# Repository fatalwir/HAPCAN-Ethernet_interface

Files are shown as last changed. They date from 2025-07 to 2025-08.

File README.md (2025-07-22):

# HAPCAN-Ethernet_interface

## TODO:
 - There is an OpenWRT package to program STM32s directly using the Mediatek SoC GPIO pins. Implement that? [https://hackaday.io/project/166859-prism/log/166980-braaains]
 - Replace the MCP3422 ADC by the MCP3423 because of the I2C address collision with BQ32000.
 - Look into replacing the CANable interface by MCP2515?

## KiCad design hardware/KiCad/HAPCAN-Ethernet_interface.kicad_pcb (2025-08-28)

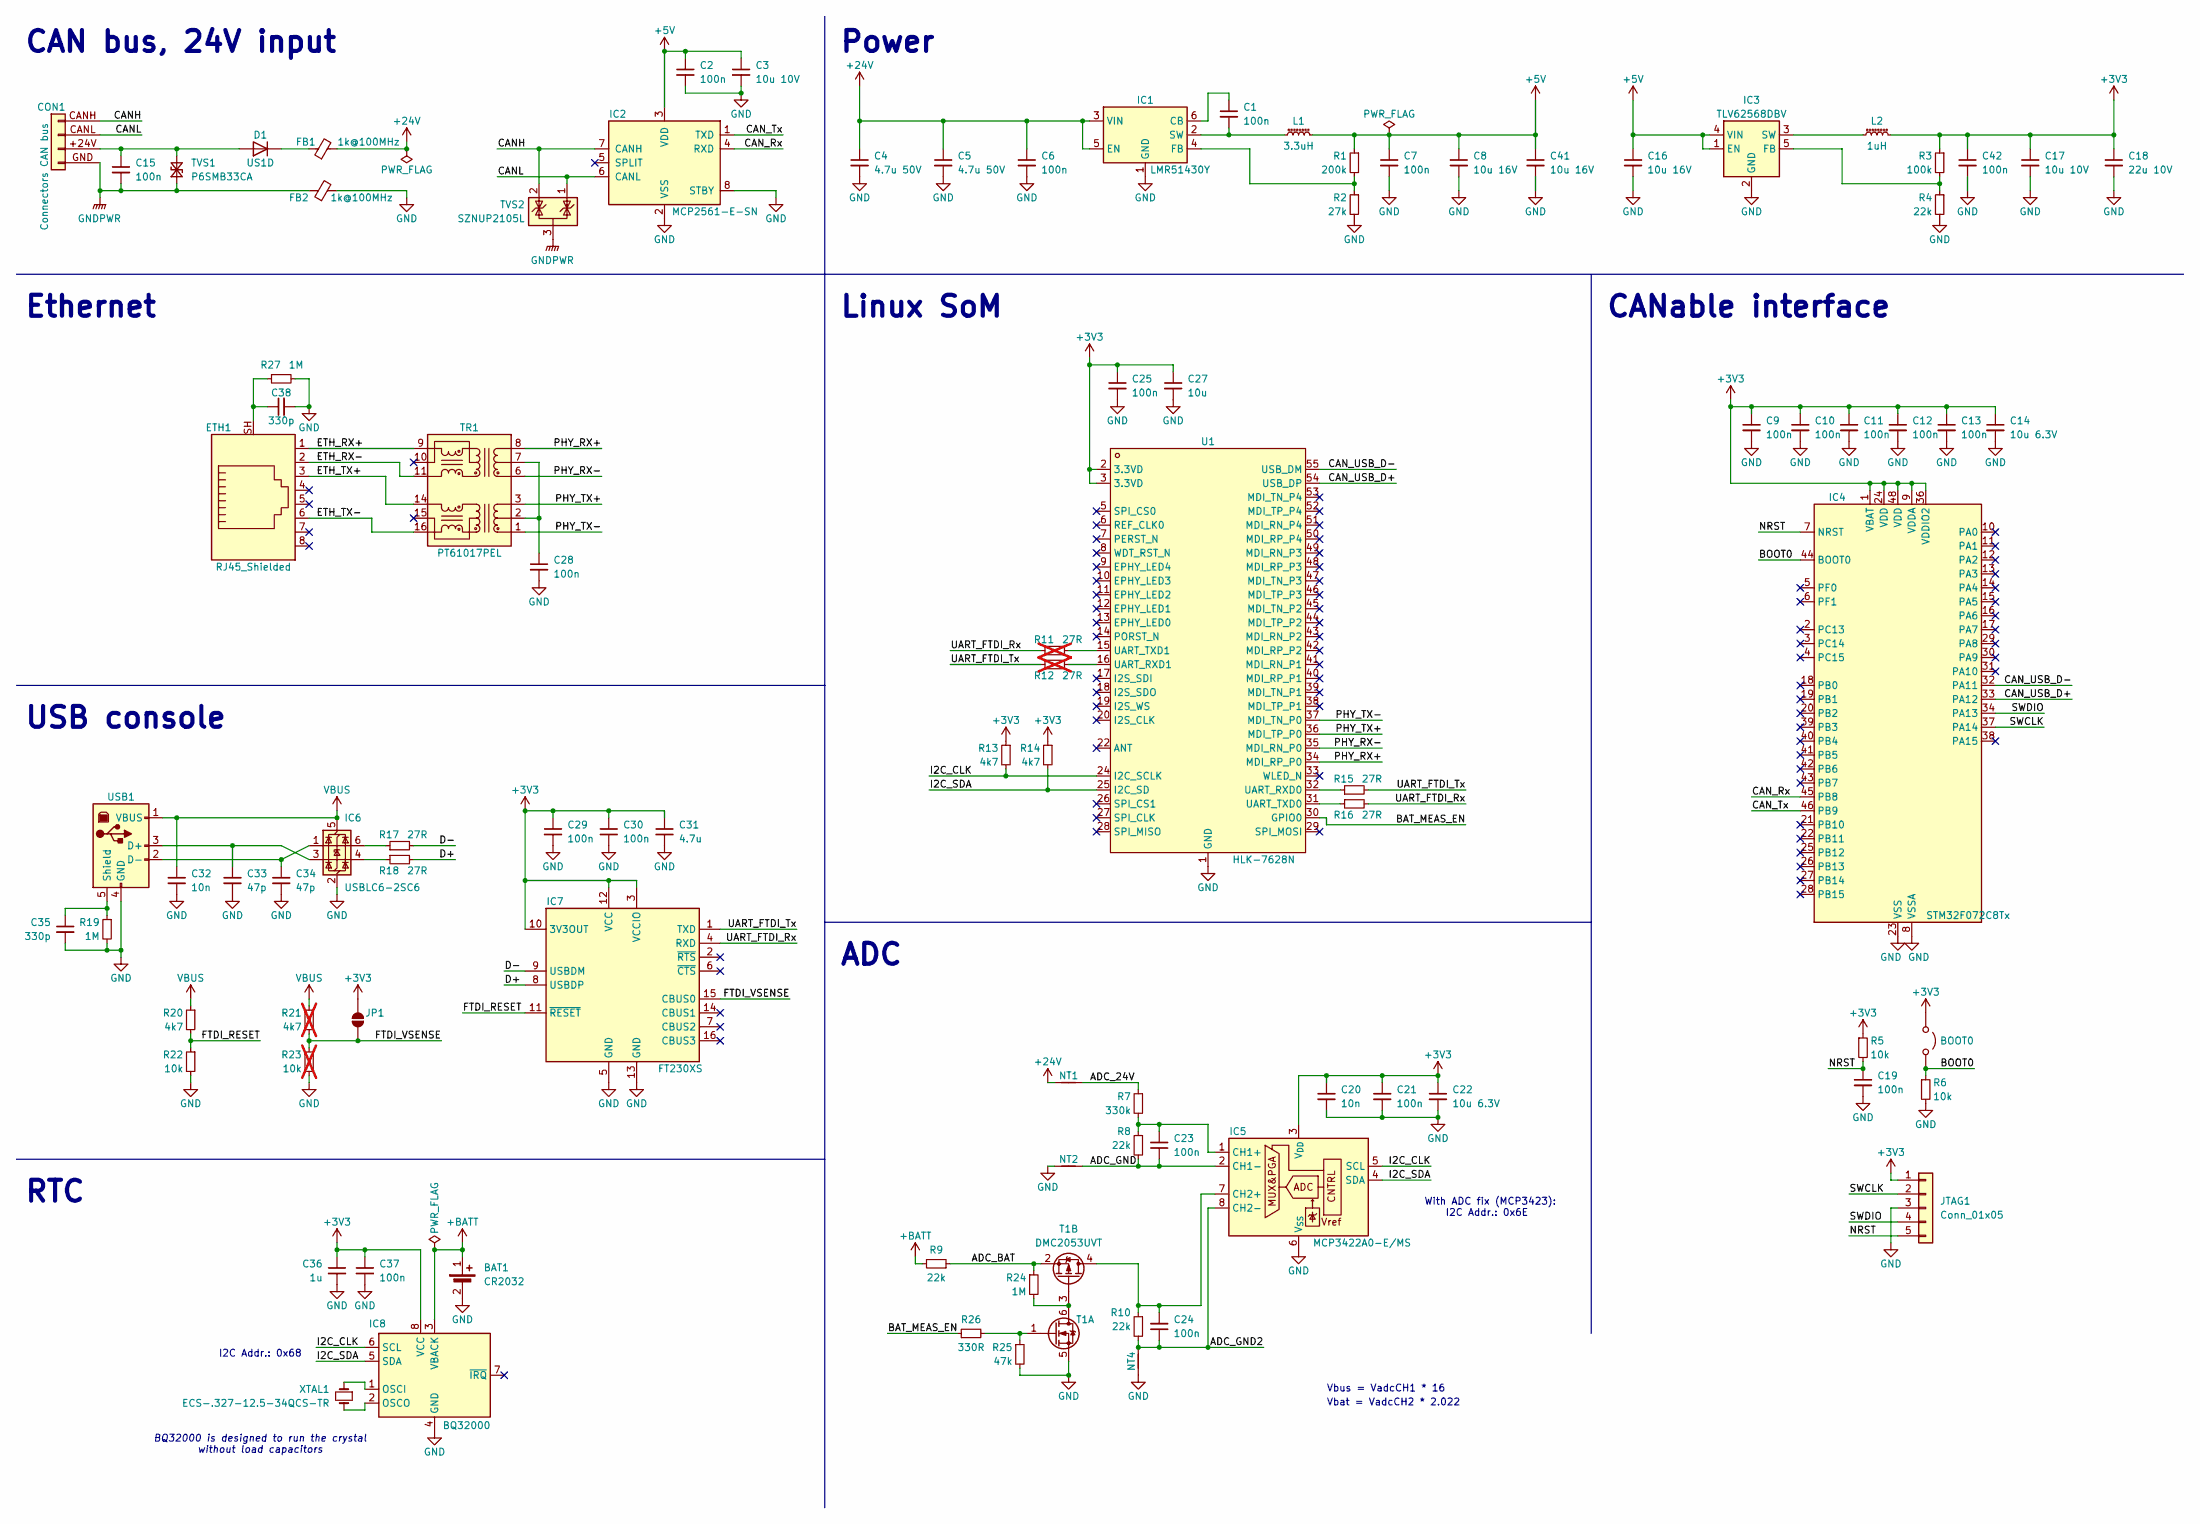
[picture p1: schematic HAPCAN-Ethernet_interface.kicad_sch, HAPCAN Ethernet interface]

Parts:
BAT1: CR2032; 1074
BOOT0: Jumper_2_Open; PinHeader_1x02_P2.54mm_Vertical
C1, C2, C6, C7, C9, C10, C11, C12, C13, C15, C19, C21, C23, C24, C25, C28, C29, C30, C37, C42: 100n; C_0603_1608Metric_Pad1.08x0.95mm_HandSolder
C3: 10u 10V; C_1206_3216Metric_Pad1.33x1.80mm_HandSolder
C4, C5: 4.7u 50V; C_1210_3225Metric_Pad1.33x2.70mm_HandSolder
C8, C16, C41: 10u 16V; C_1210_3225Metric_Pad1.33x2.70mm_HandSolder
C14, C22: 10u 6.3V; C_1206_3216Metric_Pad1.33x1.80mm_HandSolder
C17: 10u 10V; C_1210_3225Metric_Pad1.33x2.70mm_HandSolder
C18: 22u 10V; C_1210_3225Metric_Pad1.33x2.70mm_HandSolder
C20, C32: 10n; C_0603_1608Metric_Pad1.08x0.95mm_HandSolder
C27: 10u; C_1206_3216Metric_Pad1.33x1.80mm_HandSolder
C31: 4.7u; C_1206_3216Metric_Pad1.33x1.80mm_HandSolder
C33, C34: 47p; C_0603_1608Metric_Pad1.08x0.95mm_HandSolder
C35, C38: 330p; C_0603_1608Metric_Pad1.08x0.95mm_HandSolder
C36: 1u; C_0805_2012Metric_Pad1.18x1.45mm_HandSolder
CON1: Connectors CAN bus; Conn_CAN-Bus
D1: US1D; D_SMA_Handsoldering
ETH1: RJ45_Shielded; RJ45_Ninigi_GE
FB1, FB2: 1k@100MHz; L_0805_2012Metric_Pad1.15x1.40mm_HandSolder
IC1: LMR51430Y; SOT-23-6
IC2: MCP2561-E-SN; SOIC-8_3.9x4.9mm_P1.27mm
IC3: TLV62568DBV; SOT-23-5
IC4: STM32F072C8Tx; LQFP-48_7x7mm_P0.5mm
IC5: MCP3422A0-E/MS; MSOP-8_3x3mm_P0.65mm
IC6: USBLC6-2SC6; SOT-23-6_Handsoldering
IC7: FT230XS; SSOP-16_3.9x4.9mm_P0.635mm
IC8: BQ32000; SOIC-8_3.9x4.9mm_P1.27mm
JP1: SolderJumper_2_Open; SolderJumper-2_P1.3mm_Open_TrianglePad1.0x1.5mm
JTAG1: Conn_01x05; PinHeader_1x05_P2.54mm_Vertical
L1: 3.3uH; SPM7054VT
L2: 1uH; SPM7054VT
NT1, NT2, NT4: NetTie_2; NetTie-2_SMD_Pad0.5mm
R1: 200k; R_0603_1608Metric_Pad0.98x0.95mm_HandSolder
R2: 27k; R_0603_1608Metric_Pad0.98x0.95mm_HandSolder
R3: 100k; R_0603_1608Metric_Pad0.98x0.95mm_HandSolder
R4, R8, R9, R10: 22k; R_0603_1608Metric_Pad0.98x0.95mm_HandSolder
R5, R6, R22: 10k; R_0603_1608Metric_Pad0.98x0.95mm_HandSolder
R7: 330k; R_0603_1608Metric_Pad0.98x0.95mm_HandSolder
R11, R12: 27R; R_0603_1608Metric_Pad0.98x0.95mm_HandSolder; not fitted
R13, R14, R20: 4k7; R_0603_1608Metric_Pad0.98x0.95mm_HandSolder
R15, R16, R17, R18: 27R; R_0603_1608Metric_Pad0.98x0.95mm_HandSolder
R19, R24, R27: 1M; R_0603_1608Metric_Pad0.98x0.95mm_HandSolder
R21: 4k7; R_0603_1608Metric_Pad0.98x0.95mm_HandSolder; not fitted
R23: 10k; R_0603_1608Metric_Pad0.98x0.95mm_HandSolder; not fitted
R25: 47k; R_0603_1608Metric_Pad0.98x0.95mm_HandSolder
R26: 330R; R_0603_1608Metric_Pad0.98x0.95mm_HandSolder
T1: DMC2053UVT; TSOT-23-6
TR1: PT61017PEL; Transformer_Ethernet_Bourns_PT61017PEL
TVS1: P6SMB33CA; D_SMB_Handsoldering
TVS2: SZNUP2105L; SOT-23-3
U1: HLK-7628N
USB1: https://www.aliexpress.com/item/4000926155068.html; PinHeader_1x05_P2.54mm_Vertical
XTAL1: ECS-.327-12.5-34QCS-TR; Crystal_SMD_EuroQuartz_EQ161-2Pin_3.2x1.5mm_HandSoldering

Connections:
+3V3: BOOT0.1 (A), C9.1, C10.1, C11.1, C12.1, C13.1, C14.1, C17.1, C18.1, C20.1, C21.1, C22.1, C25.1, C27.1, C29.1, C30.1, C31.1, C36.1, C37.1, C42.1, IC4.1 (VBAT), IC4.9 (VDDA), IC4.24 (VDD), IC4.36 (VDDIO2), IC4.48 (VDD), IC5.3 (V_{DD}), IC7.3 (VCCIO), IC7.10 (3V3OUT), IC7.12 (VCC), IC8.8 (VCC), JP1.2 (B), JTAG1.1, L2.2, R3.1, R5.1, R13.1, R14.1, U1.2 (3.3VD), U1.3 (3.3VD)
+5V: C2.1, C3.1, C7.1, C8.1, C16.1, C41.1, IC2.3 (VDD), IC3.1 (EN), IC3.4 (VIN), L1.2, R1.1
+24V: C4.1, C5.1, C6.1, FB1.2, IC1.3 (VIN), IC1.5 (EN), NT1.1
+BATT: BAT1.1 (+), IC8.3 (VBACK), R9.2
/ADC_24V: NT1.2, R7.1
/ADC_BAT: R9.1, R24.1, T1.2 (S)
/ADC_GND: C23.1, IC5.2 (CH1-), NT2.2, R8.2
/ADC_GND2: C24.1, IC5.8 (CH2-), NT4.2, R10.2
/BAT_MEAS_EN: R26.1, U1.30 (GPIO0)
/BOOT0: BOOT0.2 (B), IC4.44 (BOOT0), R6.1
/CANH: CON1.CANH, IC2.7 (CANH), TVS2.2 (K)
/CANL: CON1.CANL, IC2.6 (CANL), TVS2.1 (K)
/CAN_Rx: IC2.4 (RXD), IC4.45 (PB8)
/CAN_Tx: IC2.1 (TXD), IC4.46 (PB9)
/CAN_USB_D+: IC4.33 (PA12), U1.54 (USB_DP)
/CAN_USB_D-: IC4.32 (PA11), U1.55 (USB_DM)
/D+: IC7.8 (USBDP), R18.2
/D-: IC7.9 (USBDM), R17.2
/ETH_RX+: ETH1.1, TR1.9 (RX-)
/ETH_RX-: ETH1.2, TR1.11 (RX+)
/ETH_TX+: ETH1.3, TR1.14 (TX-)
/ETH_TX-: ETH1.6, TR1.16 (TX+)
/FTDI_RESET: IC7.11 (~RESET), R20.2, R22.1
/FTDI_VSENSE: IC7.15 (CBUS0), JP1.1 (A), R21.2, R23.1
/I2C_CLK: IC5.5 (SCL), IC8.6 (SCL), R13.2, U1.24 (I2C_SCLK)
/I2C_SDA: IC5.4 (SDA), IC8.5 (SDA), R14.2, U1.25 (I2C_SD)
/NRST: C19.1, IC4.7 (NRST), JTAG1.5, R5.2
/PHY_RX+: TR1.8 (RD-), U1.34 (MDI_RP_P0)
/PHY_RX-: TR1.6 (RD+), U1.35 (MDI_RN_P0)
/PHY_TX+: TR1.3 (TD-), U1.36 (MDI_TP_P0)
/PHY_TX-: TR1.1 (TD+), U1.37 (MDI_TN_P0)
/SWCLK: IC4.37 (PA14), JTAG1.2
/SWDIO: IC4.34 (PA13), JTAG1.4
/UART_FTDI_Rx: IC7.4 (RXD), R11.1, R16.2
/UART_FTDI_Tx: IC7.1 (TXD), R12.1, R15.2
GND: BAT1.2 (-), C2.2, C3.2, C4.2, C5.2, C6.2, C7.2, C8.2, C9.2, C10.2, C11.2, C12.2, C13.2, C14.2, C16.2, C17.2, C18.2, C19.2, C20.2, C21.2, C22.2, C25.2, C27.2, C28.2, C29.2, C30.2, C31.2, C32.2, C33.2, C34.2, C35.2, C36.2, C37.2, C38.2, C41.2, C42.2, FB2.2, IC1.1 (GND), IC2.2 (VSS), IC2.8 (STBY), IC3.2 (GND), IC4.8 (VSSA), IC4.23 (VSS), IC4.35 (VSS), IC4.47 (VSS), IC5.6 (V_{SS}), IC6.2 (GND), IC7.5 (GND), IC7.13 (GND), IC8.4 (GND), JTAG1.3, NT2.1, NT4.1, R2.2, R4.2, R6.2, R19.2, R22.2, R23.2, R25.2, R27.2, T1.5 (S), U1.1 (GND), U1.4 (GND), U1.21 (GND), U1.23 (GND), U1.56 (GND), USB1.4 (GND)
GNDPWR: C15.2, CON1.GND, FB2.1, TVS1.1 (A1), TVS2.3 (A)
unnamed: C38.1, ETH1.SH, R27.1
unnamed: C15.1, CON1.+24V, D1.2 (A), TVS1.2 (A2)
unnamed: D1.1 (K), FB1.1
unnamed: C1.1, IC1.6 (CB)
unnamed: IC1.4 (FB), R1.2, R2.1
unnamed: C1.2, IC1.2 (SW), L1.1
unnamed: IC3.5 (FB), R3.2, R4.1
unnamed: IC3.3 (SW), L2.1
unnamed: C23.2, IC5.1 (CH1+), R7.2, R8.1
unnamed: C24.2, IC5.7 (CH2+), R10.1, T1.4 (D)
unnamed: IC6.6 (I/O1), R17.1
unnamed: IC6.4 (I/O2), R18.1
unnamed: IC8.1 (OSCI), XTAL1.1
unnamed: IC8.2 (OSCO), XTAL1.2
unnamed: R24.2, T1.3 (G), T1.6 (D)
unnamed: R25.1, R26.2, T1.1 (G)
unnamed: C28.1, TR1.2 (C_TD), TR1.7 (C_RD)
unnamed: R15.1, U1.32 (UART_RXD0)
unnamed: R12.2, U1.16 (UART_RXD1)
unnamed: R16.1, U1.31 (UART_TXD0)
unnamed: R11.2, U1.15 (UART_TXD1)
unnamed: C33.1, IC6.3 (I/O2), USB1.3 (D+)
unnamed: C34.1, IC6.1 (I/O1), USB1.2 (D-)
unnamed: C35.1, R19.1, USB1.5 (Shield)
VBUS: C32.1, IC6.5 (VBUS), R20.1, R21.1, USB1.1 (VBUS)

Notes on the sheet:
Power
With ADC fix (MCP3423): I2C Addr.: 0x6E
BQ32000 is designed to run the crystal without load capacitors
Linux SoM
ADC
CAN bus, 24V input
CANable interface
I2C Addr.: 0x68
Vbus = VadcCH1 * 16
Vbat = VadcCH2 * 2.022
USB console
RTC
Ethernet

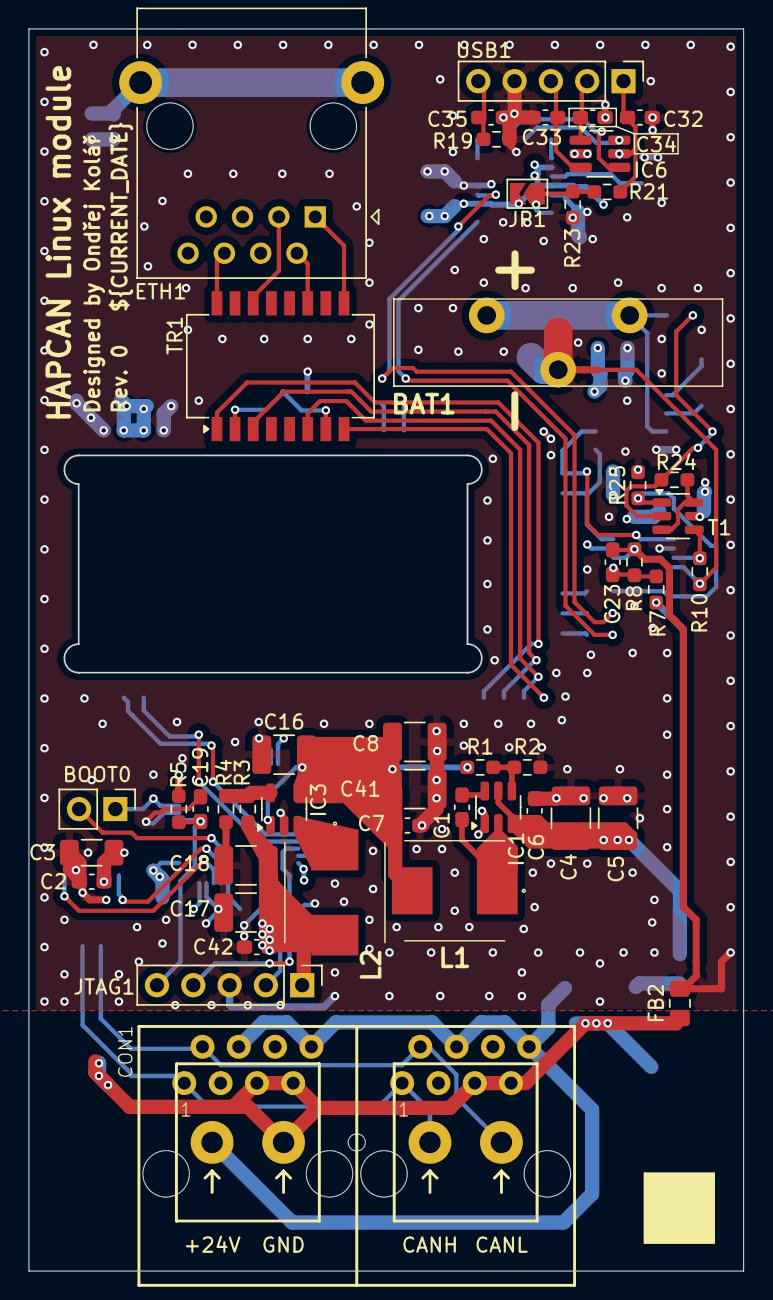
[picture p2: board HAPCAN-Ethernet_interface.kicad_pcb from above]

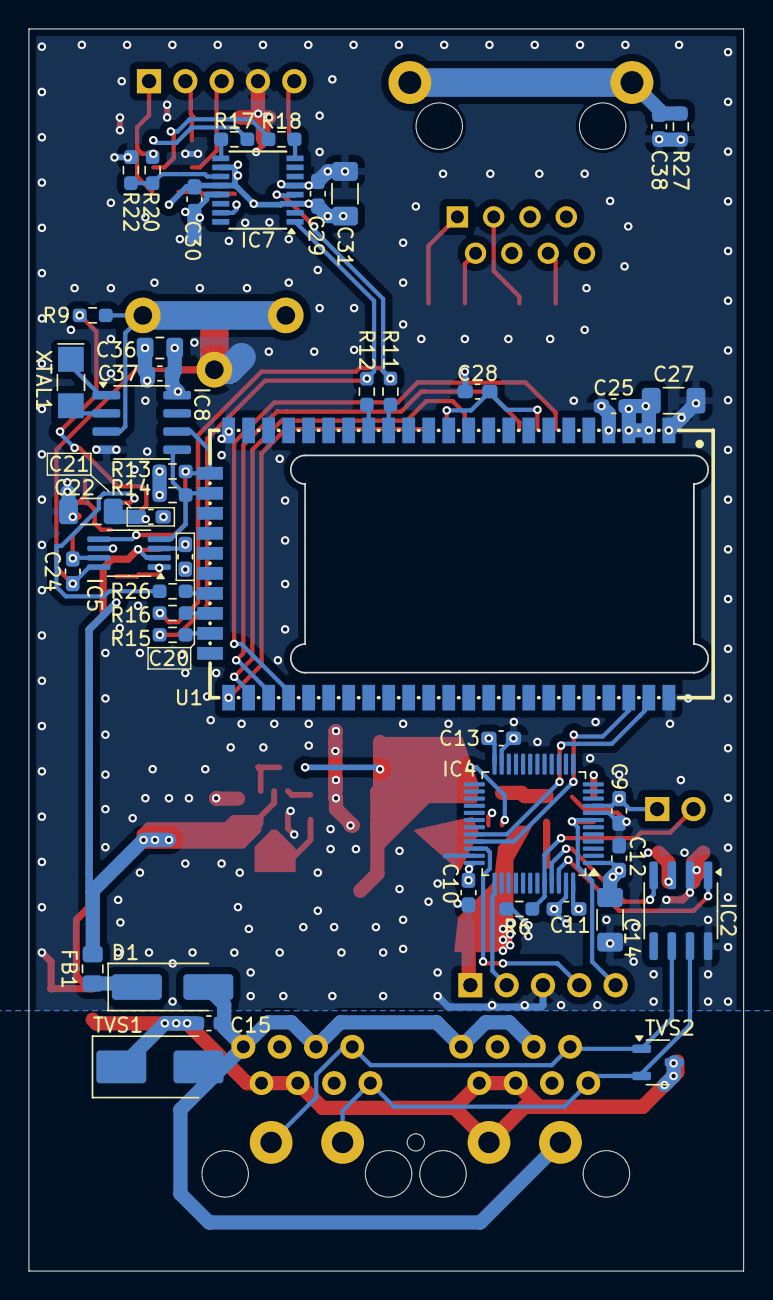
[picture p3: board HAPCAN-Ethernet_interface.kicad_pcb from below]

Board: 4 copper layers, 50.0 x 86.9 mm, 95 parts (46 on the bottom side), 62 nets.

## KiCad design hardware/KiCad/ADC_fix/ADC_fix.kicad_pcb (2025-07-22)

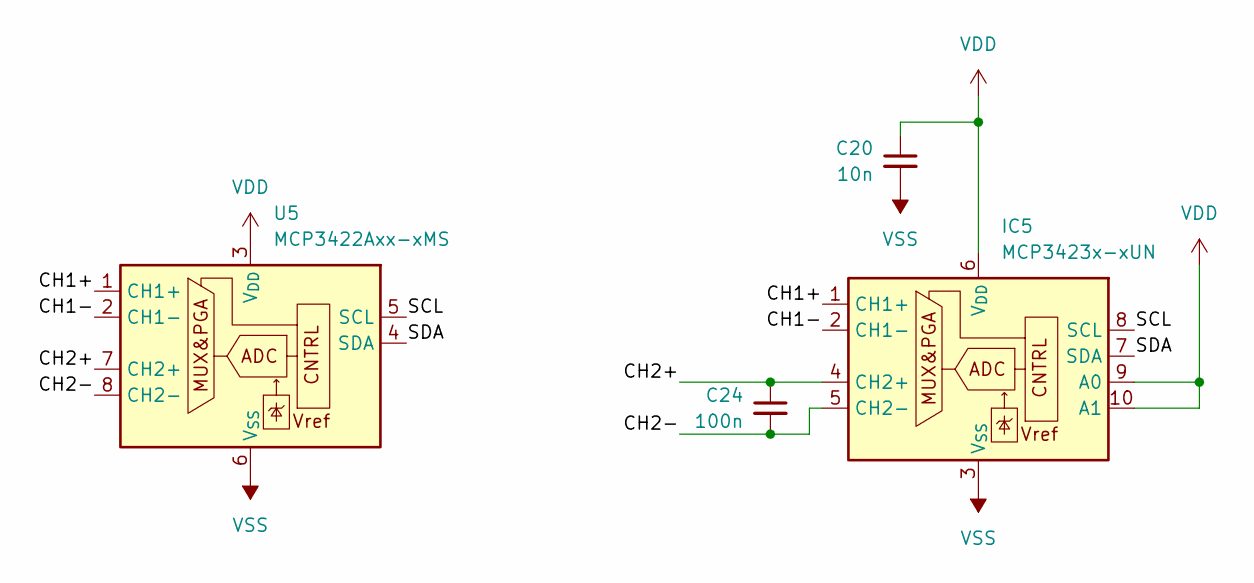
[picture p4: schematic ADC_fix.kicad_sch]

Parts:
C20: 10n; C_0603_1608Metric_Pad1.08x0.95mm_HandSolder
C24: 100n; C_0603_1608Metric_Pad1.08x0.95mm_HandSolder
IC5: MCP3423x-xUN; MSOP-10_3x3mm_P0.5mm
U5: MCP3422Axx-xMS; MSOP-8_3x3mm_P0.65mm

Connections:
/CH1+: IC5.1 (CH1+), U5.1 (CH1+)
/CH1-: IC5.2 (CH1-), U5.2 (CH1-)
/CH2+: C24.1, IC5.4 (CH2+), U5.7 (CH2+)
/CH2-: C24.2, IC5.5 (CH2-), U5.8 (CH2-)
/SCL: IC5.8 (SCL), U5.5 (SCL)
/SDA: IC5.7 (SDA), U5.4 (SDA)
VDD: C20.1, IC5.6 (V_{DD}), IC5.9 (A0), IC5.10 (A1), U5.3 (V_{DD})
VSS: C20.2, IC5.3 (V_{SS}), U5.6 (V_{SS})

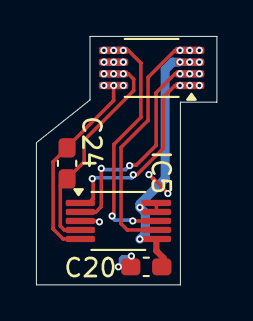
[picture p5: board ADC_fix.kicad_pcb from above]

Board: 2 copper layers, 10.0 x 13.8 mm, 4 parts (0 on the bottom side), 8 nets.

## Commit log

2024-05-04 Created KiCad project
    [HAPCAN-Ethernet_interface.kicad_pcb, HAPCAN-Ethernet_interface.kicad_sch]
2024-05-04 Added HLK-7628N symbol and footprint, MODIFICATIONS NOT FINISHED
2024-05-04 Moved KiCad .gitignore to the KiCad project directory
2024-05-06 Added 24V/3V3 step down circuit
    [HAPCAN-Ethernet_interface.kicad_pcb, HAPCAN-Ethernet_interface.kicad_sch]
2024-05-07 Made some progress in schematic, preliminary component placement on board
    [HAPCAN-Ethernet_interface.kicad_pcb, HAPCAN-Ethernet_interface.kicad_sch]
2024-05-11 Finished schematic, but needs cleanup. Started component placement on board.
    [HAPCAN-Ethernet_interface.kicad_pcb, HAPCAN-Ethernet_interface.kicad_sch]
2024-05-25 Did some work on board.
    [HAPCAN-Ethernet_interface.kicad_pcb, HAPCAN-Ethernet_interface.kicad_sch]
2024-08-02 Placed almost all footprints on the PCB
    [HAPCAN-Ethernet_interface.kicad_pcb]
2025-04-05 Updated schematic, finished the board routing
    [HAPCAN-Ethernet_interface.kicad_pcb, HAPCAN-Ethernet_interface.kicad_sch]
2025-04-07 Finished the board (Rev. 0)
    [HAPCAN-Ethernet_interface.kicad_pcb]
2025-06-30 Added DNP flag to UART1 resistors (collided connection to UART0)
    [HAPCAN-Ethernet_interface.kicad_pcb, HAPCAN-Ethernet_interface.kicad_sch]
2025-07-22 Added ADC fix flex PCB project
    [ADC_fix.kicad_pcb, ADC_fix.kicad_sch]
2025-07-22 Added ADC fix flex PCB design
    [ADC_fix.kicad_pcb, ADC_fix.kicad_sch]
2025-07-25 Added note about crystal load capacitors
    [HAPCAN-Ethernet_interface.kicad_sch]
2025-08-28 Fixed a resistor value near the ADC, added some notes to the schematic
    [HAPCAN-Ethernet_interface.kicad_pcb, HAPCAN-Ethernet_interface.kicad_sch]
